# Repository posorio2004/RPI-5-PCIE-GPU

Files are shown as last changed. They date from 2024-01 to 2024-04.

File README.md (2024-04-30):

# RPI-5-PCIE-GPU
Documentation of my work in getting an MSI Rx 580 to work on a Raspberry Pi 5

# Things I've completed:
1. Designed and manufactured a PCIE x16 adapter for the RPI 5
  - This is still being debugged currently. My adapter seems to work for an geforce 8600gt yet not the RX 580 unless I use a mining adapter which is odd. This is being investigated.
  - Initially used a generic 16 pin fpc cable however this resulted in an unstable connection. As a result I upgraded to [this](https://shop.pimoroni.com/products/pcie-flex-cable-for-nvme-base-and-raspberry-pi-5?variant=41449370910803) cable but it requried modifications to both my board (installing the fpc connector backwards) and to the cable itself (cutting off the extra two unneeded connectors). 
  - I initially tried to make the PC PSU turn on automatically however I was unsuccessful in doing so. I ended up shorting the two required pins to force the PSU to always be on.

2. Designed a basic stand for the PI and the RX 580. This stand was created to support my PCB temporarily, as I would have to recreate it once I fix the problems with the PCB.

# Tasks:

1. Hardware:
   - Creating an updated version of the board once I can fix/debug all problems with my current design
   
2. Software:
  - Installing Drivers
  - Running Programs to test functionality. (Box86/64)

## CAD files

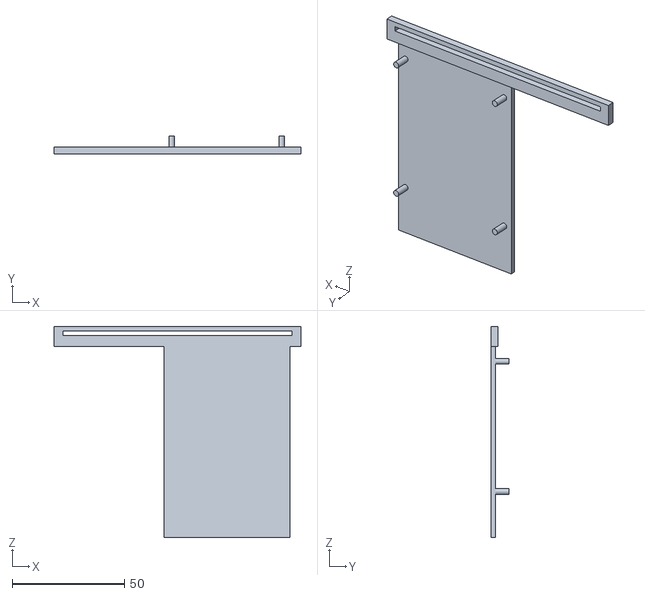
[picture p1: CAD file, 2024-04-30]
3D models/Pi Base.stl
110.0 x 8.00 x 94.0

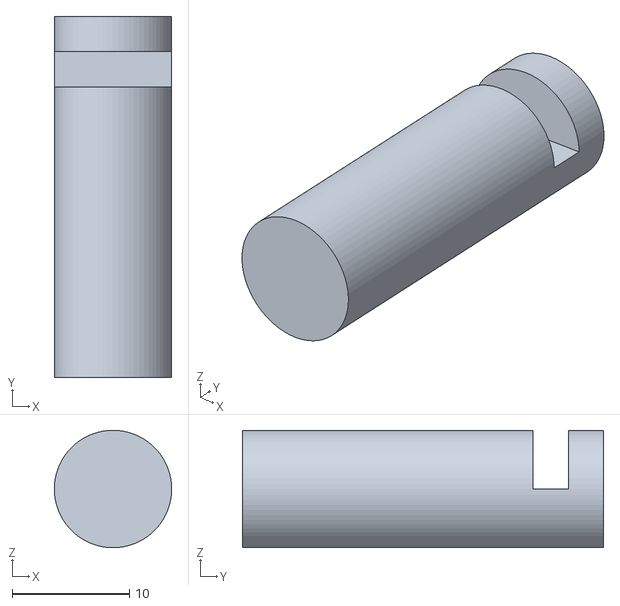
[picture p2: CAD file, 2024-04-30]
3D models/Side Support.stl
10.0 x 30.8 x 10.0

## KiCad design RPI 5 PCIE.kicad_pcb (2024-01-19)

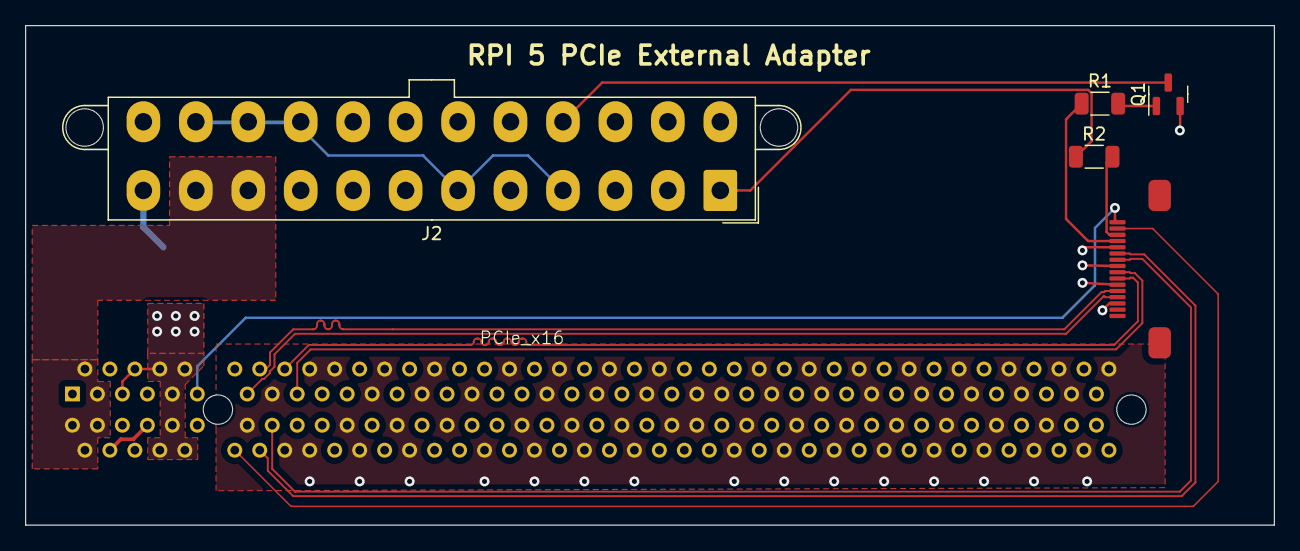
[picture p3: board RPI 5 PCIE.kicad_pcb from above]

Board: 4 copper layers, 100.0 x 40.0 mm, 6 parts (0 on the bottom side), 15 nets.

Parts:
J1: Conn_01x16; Cvilux_CF31161D0R0-05-NH
J2: ATX-24; Molex_Mini-Fit_Jr_5566-24A2_2x12_P4.20mm_Vertical
PCIe_x16: PCIe x16
Q1: MMBT3904; SOT-23
R1: 4.7k; R_1206_3216Metric
R2: 2.2k; R_1206_3216Metric

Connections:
+3.3V: J2.1 (+3.3V), J2.2 (+3.3V), J2.12 (+3.3V), J2.13 (+3.3V), PCIe_x16.A5, PCIe_x16.A6, PCIe_x16.A8, PCIe_x16.A9, PCIe_x16.A10, PCIe_x16.B8, PCIe_x16.B9, PCIe_x16.B10, R2.1
+12V: J2.10 (+12V), J2.11 (+12V), PCIe_x16.A2, PCIe_x16.A3, PCIe_x16.B1, PCIe_x16.B2, PCIe_x16.B3
/PCIE_CLKREQ_N: J1.15, PCIe_x16.B12
/PCIE_CLK_N: J1.5, PCIe_x16.A14
/PCIE_CLK_P: J1.4, PCIe_x16.A13
/PCIE_RST_B: J1.16, PCIe_x16.A11
/PCIE_RX_N: J1.8, PCIe_x16.A17
/PCIE_RX_P: J1.7, PCIe_x16.A16
/PCIE_TX_N: J1.10, PCIe_x16.B15
/PCIE_TX_P: J1.11, PCIe_x16.B14
GND: J1.3, J1.6, J1.9, J1.12, J2.3 (GND), J2.5 (GND), J2.7 (GND), J2.15 (GND), J2.17 (GND), J2.18 (GND), J2.19 (GND), J2.24 (GND), PCIe_x16.A4, PCIe_x16.A15, PCIe_x16.A18, PCIe_x16.A20, PCIe_x16.A23, PCIe_x16.A24, PCIe_x16.A27, PCIe_x16.A28, PCIe_x16.A31, PCIe_x16.A34, PCIe_x16.A37, PCIe_x16.A38, PCIe_x16.A41, PCIe_x16.A42, PCIe_x16.A45, PCIe_x16.A46, PCIe_x16.A49, PCIe_x16.A51, PCIe_x16.A54, PCIe_x16.A55, PCIe_x16.A58, PCIe_x16.A59, PCIe_x16.A62, PCIe_x16.A63, PCIe_x16.A66, PCIe_x16.A67, PCIe_x16.A70, PCIe_x16.A71, PCIe_x16.A74, PCIe_x16.A75, PCIe_x16.A78, PCIe_x16.A79, PCIe_x16.A82, PCIe_x16.B4, PCIe_x16.B7, PCIe_x16.B13, PCIe_x16.B16, PCIe_x16.B18, PCIe_x16.B21, PCIe_x16.B22, PCIe_x16.B25, PCIe_x16.B26, PCIe_x16.B29, PCIe_x16.B32, PCIe_x16.B35, PCIe_x16.B36, PCIe_x16.B39, PCIe_x16.B40, PCIe_x16.B43, PCIe_x16.B44, PCIe_x16.B47, PCIe_x16.B49, PCIe_x16.B52, PCIe_x16.B53, PCIe_x16.B56, PCIe_x16.B57, PCIe_x16.B60, PCIe_x16.B61, PCIe_x16.B64, PCIe_x16.B65, PCIe_x16.B68, PCIe_x16.B69, PCIe_x16.B72, PCIe_x16.B73, PCIe_x16.B76, PCIe_x16.B77, PCIe_x16.B80, Q1.2 (E)
unnamed: J1.13, R1.1
unnamed: J1.14, R2.2
unnamed: J2.16 (PS_ON#), Q1.3 (C)
unnamed: Q1.1 (B), R1.2

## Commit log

2024-01-13 Uploaded Empty Project Files
    [RPI 5 PCIE.kicad_pcb, RPI 5 PCIE.kicad_sch]
2024-01-13 Created Schematic
    [RPI 5 PCIE.kicad_sch]
2024-01-13 Started PCB
    [RPI 5 PCIE.kicad_pcb, RPI 5 PCIE.kicad_sch]
2024-01-14 Attempted PCB Design
    Realized that a 4-layer PCB is required. Will continue research into impedance controlled PCBs
    [RPI 5 PCIE.kicad_pcb, RPI 5 PCIE.kicad_sch]
2024-01-14 Updated PCB to 4-layer Board
    [RPI 5 PCIE.kicad_pcb]
2024-01-14 Small PCB updates
    [RPI 5 PCIE.kicad_pcb]
2024-01-15 Updated Tracer Width to JLCPCB recommendations
    [RPI 5 PCIE.kicad_pcb]
2024-01-19 Finished PCB v1
    This was the first prototype to be sent to JLC PCB
    [RPI 5 PCIE-B_Cu.gbl, RPI 5 PCIE-B_Mask.gbs, RPI 5 PCIE-B_Paste.gbp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]
2024-04-30 Added 3d support models
    [Pi Base.stl, Side Support.stl]
2024-04-30 Fixed Pi Base Model
    [Pi Base.stl]
